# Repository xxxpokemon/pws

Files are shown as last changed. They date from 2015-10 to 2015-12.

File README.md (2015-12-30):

#Profielwerkstuk

##PWM

Een klasse D versterker maakt gebruik van puls breedte modulatie (pwm). Het uitgangssignaal is een blokgolf, waarbij de breedte van het blok evenredig varieert met het geluidssignaal. In dit project wordt de blokgolf door een arduino gemaakt. De arduino is een bordje waarop een microcontrolerchip (atmega 328p) werkt. 

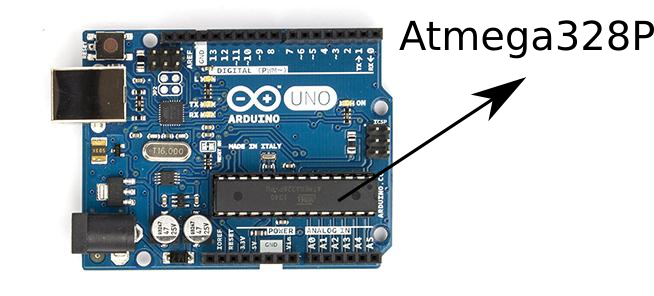
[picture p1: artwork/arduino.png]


Het voordeel is dat deze zowel een analoge ingang als digitale uitgang heeft (pwm). Het te versterken signaal kunnen we inlezen met de analoge ingang en omzetten naar een pwm signaal. Dit alles door te programmeren in C. Echter stuiten wij op het volgende probleem. De arduino programmeeromgeving (ide) maakt gebruik van een dialect van de programmeertaal c en geeft geen toegang tot alle mogelijkheden van de atmegachip. Ook niet degene die wij nodig hebben. 
Te weten: De standaard pwm frequentie is veel te laag, deze ligt in het hoorbare gebied (freq. lager dan 20 kHz). Bij pwm willen we een gemiddelde hoorbaar maken en niet de puls zelf. Hiervoor moet de frequentie dus ver boven het hoorbare gebied liggen. Door de puls zelf weg te filteren houden wij het gemiddelde over wat het gewenste signaal is. 

####Arduino PWM MET LED

https://youtu.be/I2XWtsqLY4k

###Werking pwm op atmega 328p

Wij maken gebruik van de [datasheet](http://www.atmel.com/images/atmel-8271-8-bit-avr-microcontroller-atmega48a-48pa-88a-88pa-168a-168pa-328-328p_datasheet_complete.pdf) voor de atmega328p. Dit is gebruikelijk in de elektronica om gebruik te maken van de datasheets van onderdelen. Hier staat de werking van de atmega328p beschreven. 
De pwm maakt gebruik van een telregister (TCR). Deze telt van 0 tot TOP en begint daarna weer bij nul (ad infinitum). De uitgang kan gekoppeld worden aan de output compare register (OCR), deze bevat een zeker getal. Als TCR tussen 0 en dit getal is, dan is de uitgangspin hoog en anders laag. Dus de verhouding OCR TOP bepaalt de breedte van de puls. 
De atmega328p heeft 3 pwm registers, twee 8-bits en één 16-bits. 8-bits is een te lage resolutie voor goed geluid. 16-bits is CD kwaliteit, maar dan wordt de frequentie te laag. 
Het tellen gaat met de snelheid van de central prossesing unit (CPU) klok. Deze is 16 MHz. Dus 1 periode duurt: 65535 * (1/16000000)= 0.0040959375 seconden = 243 Hz. Dit is een extreem lage frequentie. Dit zit vol in het hoorbare gebied. Beetje jammer. Dus is het voordelig als we het register in de 9-bits modus zetten. Dus 512 * (1/16000000) = 0.000032 seconden = 31250 Hz. Dit vinden wij acceptabel. Nu moeten we de atmega 328p dus instellen op 9-bits FAST PWM. Hoe dit moet staat beschreven in de datasheet paragraaf 16.11 ofzo. Hier staat welke bits hoe ingesteld moeten worden. Om de TCR in non-inverting pwm mode te zetten moet de 8e bit van het TCCR1A register aan zijn. Om de 9-bits FAST PWM aan te zetten moet bit 1 aan en in register TCCR1B moet bit 3 aan. Om ze snel mogelijk te tellen (hoge PWM frequentie) moet de pre-scaler op delen door 1 staan (dit is bit 0 in TCCR1B). 
```c
	TCCR1A = 0b10000010;
	TCCR1B = 0b00001001;
```
Dit kan netter met voorgedefinieerde variabelen.
```c
	TCCR1A = ((1 << COM1A1) | (1<<COM1B1)|(1 << WGM11));
  	TCCR1B = ((1 << WGM12) | (1 << CS10));
```
Zie verder broncode. Amplifier.ino 

##Polariteit 

Geluidssignalen hebben zowel positieve als negatieve polariteit. De analoog digitaal omzetter van de "adc" atmega kan alleen positief aan. De pwm produceert ook alleen maar positieve signalen. Zowel voor de in/uitgang moeten we een oplossing bedenken.

###ingang

Dit betekent dat we een biass moeten toevoegen. Wat ervoor zorgt dat het negatieve deel van het geluidssignaal ook positief wordt. 

###uitgang

H-brug
in de H-brug gebruiken we vermogen transistors, ook deze kunnen niet direct door de arduino worden aangestuurd. (Want de stroom die door basis moet lopen moet groot zijn, om de transisitor helemaal aan te zetten)
NPN en PNP transistor.
We maken gebruik van een BJT (bipolar junction transistor) 

De adruino moet dus twee uitgangen hebben, omdat we gebruik maken van een H-brug. Een plus PWM (PWM A) en een min PWM (PWM B). Zo kunnen we ook het positieve signaal negatief maken. 
Het ingangssignaal heeft een offset gekregen. Wat boven de offset uitkomt gaat naar PWM A en wat onder de offset uitkomt wordt naar PWM B gestuurd. 

Formule:

PWM A: signaal - offset 
PWM B: offset - signaal 

Schakelschema:

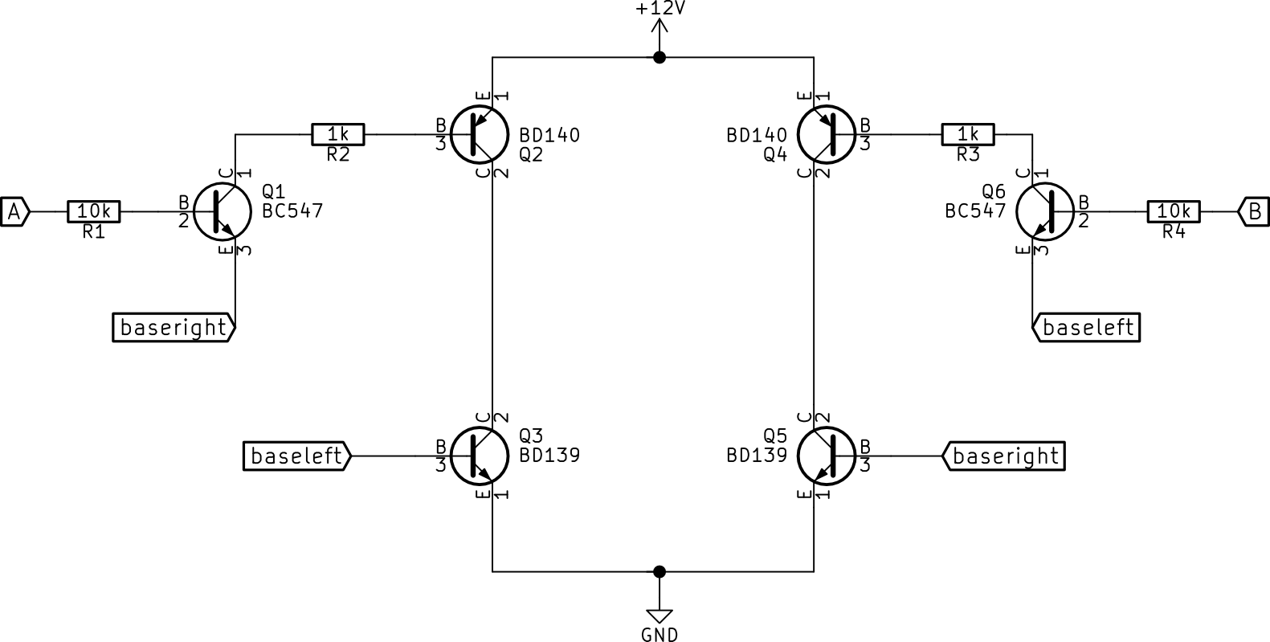
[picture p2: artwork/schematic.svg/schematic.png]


Breadboard:

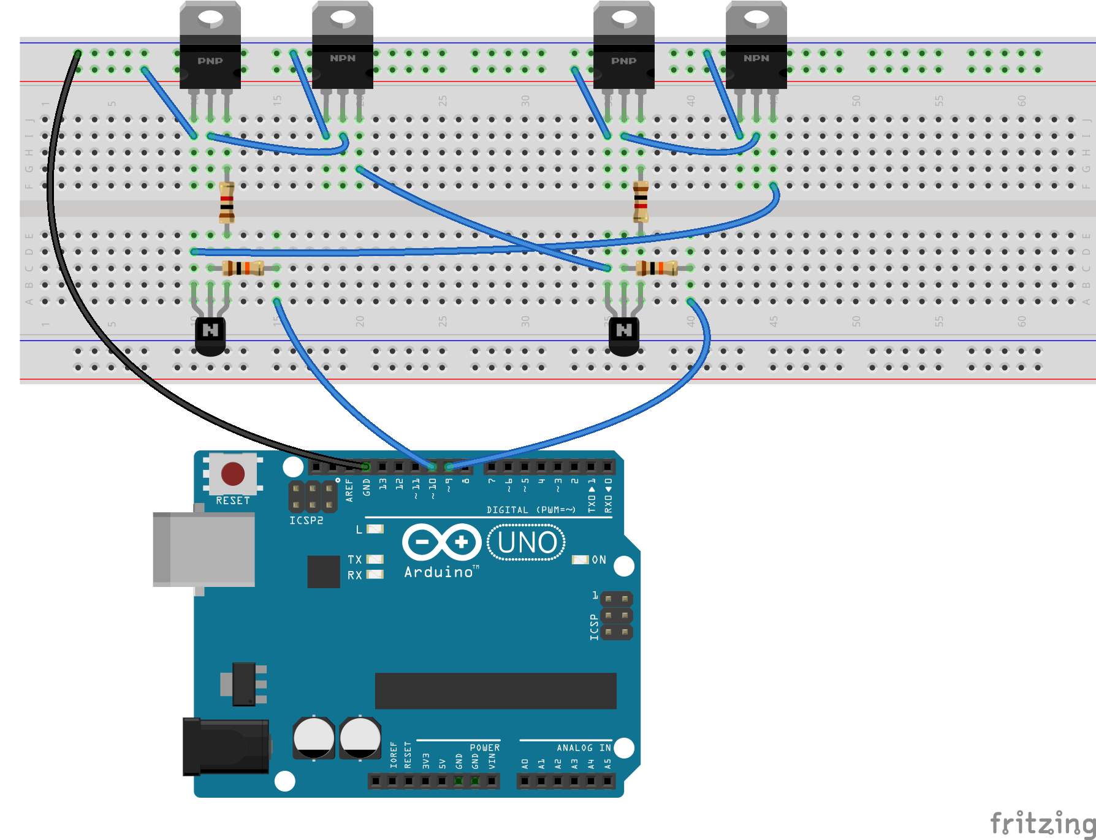
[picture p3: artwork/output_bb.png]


##variabele spanning

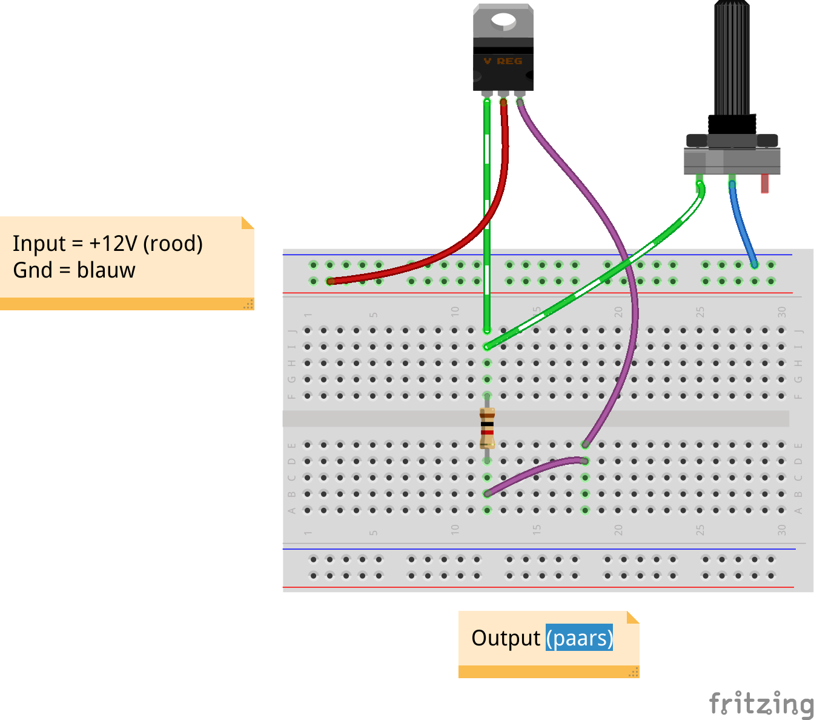
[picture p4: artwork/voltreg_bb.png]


##Voortgang:

<img src="./artwork/IMG_20151007_190225.jpg" alt="Drawing" width=500px"/>
##todo
1. ~~transistor toevoegen
de pwm zit op pin 5, kan niet genoeg stroom leveren voor luidspreker
dus gebruiken we een transistor.~~
2. ~~timer interrupt~~
3. ~~frequentie van pwm omhoog~~
4. schema afmaken 
5. ~~arduino programmeren (PWM A, PWM B)~~
6. Behuizing
7. Grafieken maken
8. Printplaat maken 

##schema

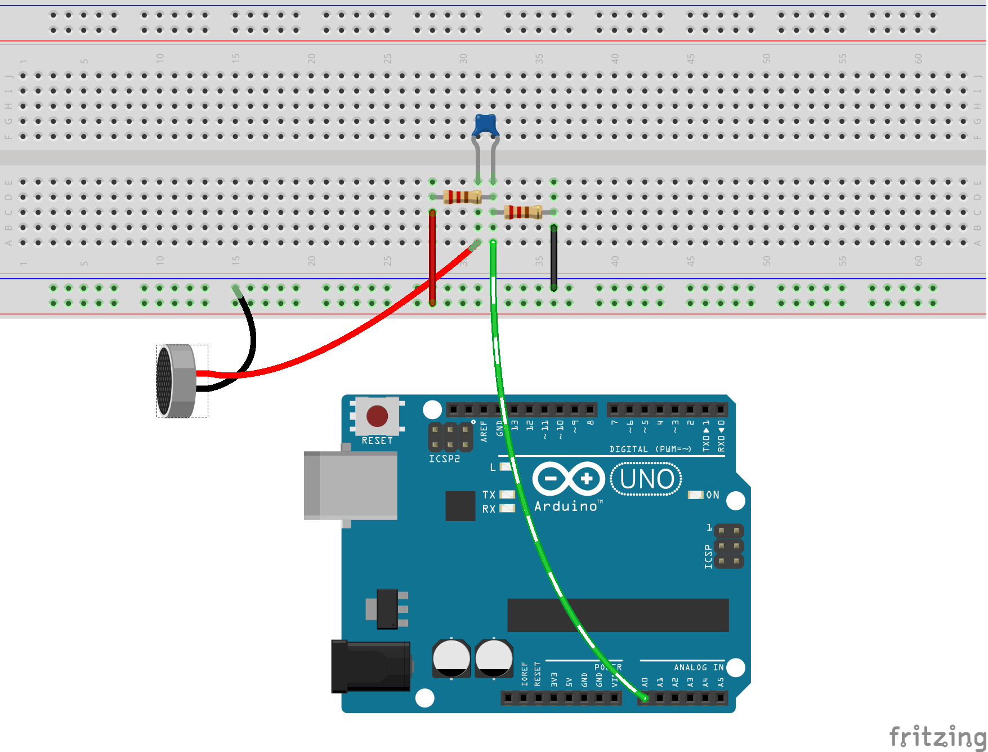
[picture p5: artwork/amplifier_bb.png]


opties:

1. kant en klaar d versterker https://www.kiwi-electronics.nl/componenten-onderdelen/geluid-muziek-onderdelen/stereo-20w-class-d-audio-versterker-MAX9744
	zelf volume knop maken met I2C 
2. zelf klasse d versterker bouwen https://www.youtube.com/watch?v=CrAB9rIcakE
3. gadgettronix klasse A/B 30 watt http://www.gadgetronicx.com/diy-stereo-amplifier-circuit-diagram/
- long tailed pair
- miller cap, voltage amplification stage
- push/pull stage, darlington

Voor/nadelen 

Klasse D: geen koeling nodig, want uitgangstrap alleen aan en uit dus geen weerstand geen hitte. Componenten kunnen dicht bij elkaar. Kan kleiner. Batterij voeding voldoende. Wel programeren. 
Arduino programeren. In Arduino IDE. Aansluiten op transistor, want chip kan geen stroom leveren. 

Klasse A/B: Groot, koeler nodig., want hitte. Grote voeding. Niet programeren.

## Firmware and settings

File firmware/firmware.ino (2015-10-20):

#define ANALOG0 0

#define OFFSET 256
        

void setup() 
{
  // put your setup code here, to run once:
  //ADC setup - here
  ADMUX = 0b00000000;
  ADCSRA = ((1 << ADEN) | (1 << ADSC) | (1 << ADATE) | (1 << ADIE)); 
  ADCSRB = 0b00000000;
  //setPwmFrequency(5, 1);
  //https://www.arduino.cc/en/Tutorial/SecretsOfArduinoPWM
  //we moeten de pwm freq naar 60kHz doen
  //TCCR1A=0b10000011;
  //TCCR1B=0b00001001;

  TCCR1A = ((1 << COM1A1) | (1<<COM1B1)|(1 << WGM11));
  TCCR1B = ((1 << WGM12) | (1 << CS10));
  DDRB = (1 << 1)| (1<<2);//pin b1 & pin b2 output
    
}
  
uint16_t val;
  
void loop() 
{
 
}

// Interrupt service routine for the ADC completion
ISR(ADC_vect)
{

  // Must read low first
  val = ADCL | (ADCH << 8);
  //val is nu 10 bits , we willen 9 bits (we moeten door 2 delen) 
  val = val/2;
  if (val >= OFFSET) {
    OCR1B = 0;    //eerst uit, anders kortsluiting 
    OCR1A = val - OFFSET; 
   } else {
    OCR1A = 0;
    OCR1B = OFFSET - val; 
   }
}

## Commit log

2015-10-12 new file: artwork/amplifier_bb.png new file: breadboard/amplifier.fzz modified: firmware/firmware.ino
    [amplifier.fzz]
2015-10-12 new file: artwork/arduino.png
2015-10-20 modified: breadboard/amplifier.fzz modified: firmware/firmware.ino
    [amplifier.fzz]
2015-10-20 new file: breadboard/H.fzz
    [H.fzz]
2015-10-20 deleted: breadboard/H.fzz
    [H.fzz]
2015-10-21 new file: artwork/schematic.svg/schema.sch.svg new file: artwork/schematic.svg/schematic.png
2015-10-21 modified: artwork/schematic.svg/schematic.png
2015-10-24 modified: artwork/schematic.svg/schema.sch.svg new file: artwork/voltreg_bb.png new file: breadboard/voltreg.fzz
    [voltreg.fzz]
